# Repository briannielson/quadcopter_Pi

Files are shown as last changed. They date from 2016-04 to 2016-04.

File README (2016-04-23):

PiCopter v0.1

Ground Control is a Linux based controller to parse linux kernel events and send out Yaw, Pitch, Roll data over UDP.

Pi Control is a Raspbian based quad controller to receive input from the Ground Control module and translate output to the individual motors.

Pi Control contains a sub module called imu_sensor, being a modified version of Richard Hirst's modified version of Jeff Rowberg's I2CdevLib.

To setup, you need to:
	- Deploy ground control to your controller
		- Modify controller.c to point to your device
			Line 49: char * fd_source = "/dev/input/event10";
		- Modify udpclient.c to point to your Pi Copter
			Line 29: host= (struct hostent *) gethostbyname((char *)"192.168.1.2");
		- run "make" in the directory ground_control
			-- This compiled on Ubuntu 15.10. This was not tested on any other release.
			-- On other Linux releases, you may or may not need to have the gcc 
			-- option '-D_GNU_SOURCE' in the Makefile.
	- Deploy Pi Control to your Pi Copter
		- run "make" in the directory pi_control
			-- This compiled on Ubuntu 15.10. This was not tested on any other release.
			-- On other Linux releases, you may or may not need to have the gcc 
			-- option '-D_GNU_SOURCE' in the Makefile.
		- run "make" in the directory pi_control/imu_sensor
			-- THIS IS C++ CODE AND A MAJORITY OF IT IS NOT OFFICIALLY PART OF MY RELEASE.
			-- USE AT YOUR OWN RISK. REPORT ANY BUGS TO Richard Hirst (his README is included)

To run:
	- run "sudo ./dmp" in the directory "pi_control/imu_sensor"
	- in another terminal, run "sudo ./control" in the directory "pi_control"
	- on your laptop (ground control), run "sudo ./control" in the directory "ground_control"
	
Hardware:
	- Raspberry Pi B+
	- 12A BLHELI ESC x4
	- Arris MT1806 brushless motor x4
	- 5030 5x3 Propellors x8
	- SanDisk 8GB Class 10 MicroSDHC
	- ARRIS 200x300x3.0mm Carbon Fiber Plate
	- Addicore 5V 1.5A Voltage Regulator L7805CV
	- SMAKN Arduino GY-521 MPU6050 IMU
	- Arducam 5mp OV5647 Mini Camera
	- Venom 20C 3S 2100mAh 11.1V LiPo Battery
	
Compiled and written by Brian Bauman, with significant assistance based on other projects. Freely available to anyone to mess with. If you have any questions, shoot me an email (brian.bauman@cmich.edu), or post an issue on my github. If you need some help deploying this to your own quad, I can lend some assistance, but honestly do not run this version of the code. The PID control is currently out of whack and can be EXTREMELY dangerous (I was in the hospital earlier today because the algorithm exploded and the quad took a decent chunk of my finger off).

I do not take any responsibility in the event of any injuries if you use this project.

PiCopter
--ground_control
	-- main: Starts threads, critical variables, and atomic functions for critical values
	-- controller: Reads input from /dev/input/event** and sets critical variables
	-- udpclient: Reads critical variables and sends yaw, pitch, and roll values to quad
-- pi_control
	-- main: Starts threads, critical variables, and atomic functions for critical values
	-- motorout: Translates input from critical variables to PWM outputs. Also contains PID algorithms currently
	-- server: Listens on port 5000 by default for control information from ground_control
	-- pwm: library used in RPIO (http://pythonhosted.org/RPIO)
	-- imu_sensor
		-- MPU6050, MPU76050_6Axis_MotionApps20: Contains DMP bits to program MPU6050, as well as core functions
		-- helper_3d_math: used to calculate quaternions, euler, and orientation data from raw MPU6050 data
		-- I2Cdev: I2CdevLib for basic I2C communication
		-- dmp: translated Arduino sketch to work in C++, currently configured to write yaw, pitch, roll values to imuData
		-- imuData: data output file to send data from C++ to C program (pi_control/motorout.c)

Resources / code used:

https://solenerotech1.wordpress.com/2013/09/09/tutorialhow-to-control-a-brushless-motor-with-raspberry-pi/ 
https://pythonhosted.org/RPIO/pwm_py.html 
https://www.cdiweb.com/datasheets/invensense/MPU-6050_DataSheet_V3 4.pdf 
http://www.i2cdevlib.com/devices/mpu6050#source 
https://github.com/jrowberg/i2cdevlib/tree/master/Arduino/MPU6050
http://matrixsust.blogspot.com/2011/10/udp-server-client-in-c.html 
https://github.com/metachris/RPIO/tree/master/source/c_pwm 
https://github.com/richardghirst/PiBits/tree/master/MPU6050-Pi-Demo 
http://ctms.engin.umich.edu/CTMS/index.php?example=Introduction&section=ControlPID 
http://www.linuxjournal.com/article/6429

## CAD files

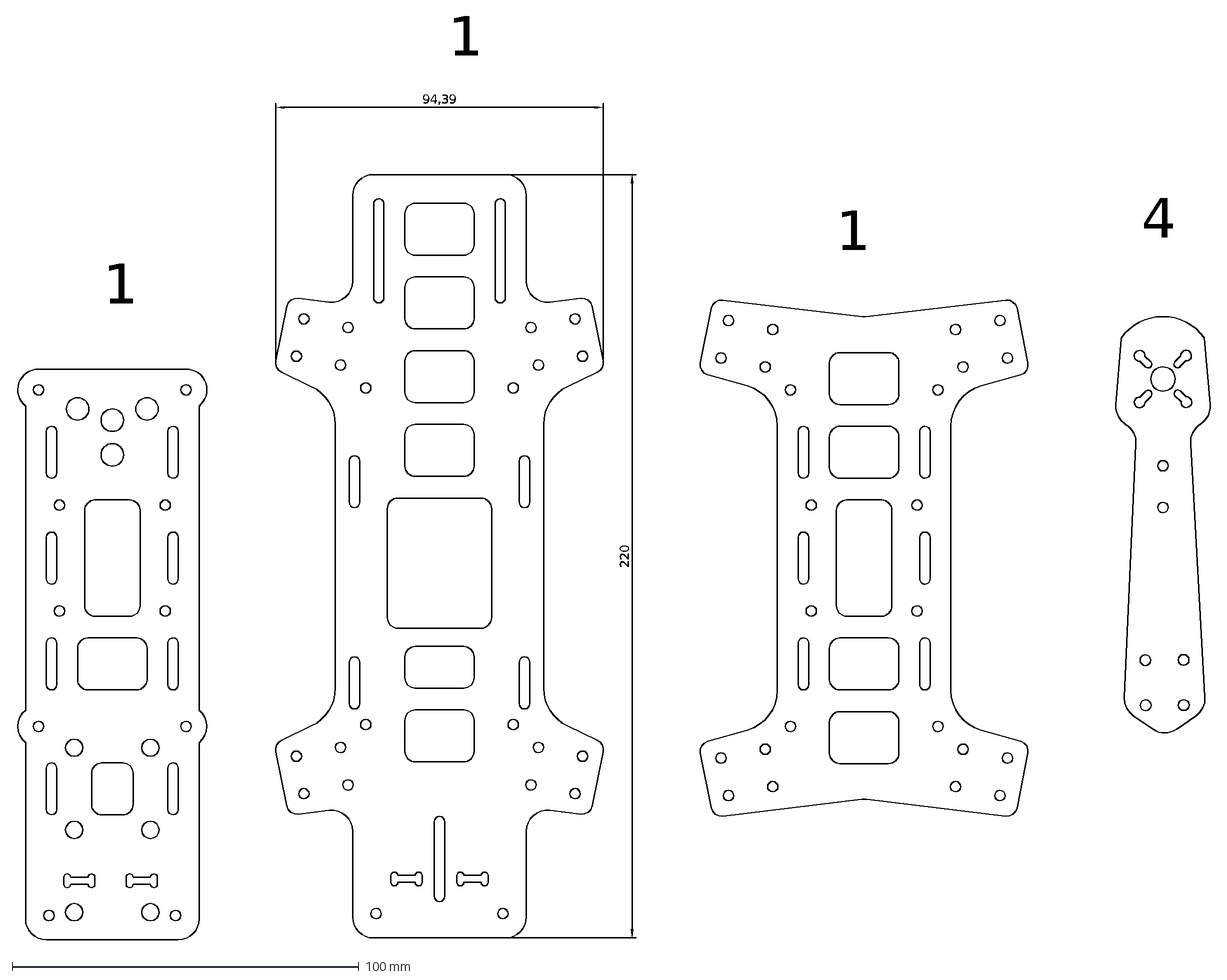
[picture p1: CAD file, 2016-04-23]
composite.dxf
220
94,39
1
4

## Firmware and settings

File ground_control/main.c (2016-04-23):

/*
 * @author: Brian Bauman
 *
 * main program to allow writing from
 * controller to the shared struct which
 * stores the axes values and reading
 * from the UDP client to send values
 * to the server.
 */

#include <stdio.h>
#include <pthread.h>
#include <signal.h>
#include <unistd.h>
#include "controller.h"
#include "udpclient.h"
#include "main.h"
#include <stdatomic.h>

volatile sig_atomic_t stop = 0;
atomic_int lock = 1;

void sigterm_catch(int signum)
{
	stop = 1;
}

int main(void)
{
	joysticks.roll = 0;
	joysticks.throttle = 0;
	joysticks.yaw = 0;
	joysticks.pitch = 0;

	pthread_t pth_ctrl;
	pthread_t pth_udp;

	// worker thread for controller
	pthread_create(&pth_ctrl, NULL, controller_mod, 0);
	sleep(2);
	pthread_create(&pth_udp, NULL, udp_client, 0);

	signal(SIGINT, sigterm_catch);

	while (!stop);

	printf("Terminating threads...\n");

	pthread_join(pth_ctrl, NULL);
	pthread_join(pth_udp, NULL);

	release();

	return 0;
}

void wait(void)
{
	while (lock < 1);
	lock-=1;
}

void release(void)
{
	lock+=1;
}

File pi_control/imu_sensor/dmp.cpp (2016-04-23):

#include <stdio.h>
#include <stdlib.h>
#include <unistd.h>
#include <stdint.h>
#include <string.h>
#include <math.h>
#include "I2Cdev.h"
#include "MPU6050_6Axis_MotionApps20.h"
#include <iostream>
#include <fstream>
using namespace std;

// class default I2C address is 0x68
// specific I2C addresses may be passed as a parameter here
// AD0 low = 0x68 (default for SparkFun breakout and InvenSense evaluation board)
// AD0 high = 0x69
MPU6050 mpu;

// uncomment "OUTPUT_READABLE_QUATERNION" if you want to see the actual
// quaternion components in a [w, x, y, z] format (not best for parsing
// on a remote host such as Processing or something though)
//#define OUTPUT_READABLE_QUATERNION

// uncomment "OUTPUT_READABLE_EULER" if you want to see Euler angles
// (in degrees) calculated from the quaternions coming from the FIFO.
// Note that Euler angles suffer from gimbal lock (for more info, see
// http://en.wikipedia.org/wiki/Gimbal_lock)
//#define OUTPUT_READABLE_EULER

// uncomment "OUTPUT_READABLE_YAWPITCHROLL" if you want to see the yaw/
// pitch/roll angles (in degrees) calculated from the quaternions coming
// from the FIFO. Note this also requires gravity vector calculations.
// Also note that yaw/pitch/roll angles suffer from gimbal lock (for
// more info, see: http://en.wikipedia.org/wiki/Gimbal_lock)
#define OUTPUT_READABLE_YAWPITCHROLL

// uncomment "OUTPUT_READABLE_REALACCEL" if you want to see acceleration
// components with gravity removed. This acceleration reference frame is
// not compensated for orientation, so +X is always +X according to the
// sensor, just without the effects of gravity. If you want acceleration
// compensated for orientation, us OUTPUT_READABLE_WORLDACCEL instead.
//#define OUTPUT_READABLE_REALACCEL

// uncomment "OUTPUT_READABLE_WORLDACCEL" if you want to see acceleration
// components with gravity removed and adjusted for the world frame of
// reference (yaw is relative to initial orientation, since no magnetometer
// is present in this case). Could be quite handy in some cases.
//#define OUTPUT_READABLE_WORLDACCEL

// uncomment "OUTPUT_TEAPOT" if you want output that matches the
// format used for the InvenSense teapot demo
//#define OUTPUT_TEAPOT

// MPU control/status vars
bool dmpReady = false;  // set true if DMP init was successful
uint8_t mpuIntStatus;   // holds actual interrupt status byte from MPU
uint8_t devStatus;      // return status after each device operation (0 = success, !0 = error)
uint16_t packetSize;    // expected DMP packet size (default is 42 bytes)
uint16_t fifoCount;     // count of all bytes currently in FIFO
uint8_t fifoBuffer[64]; // FIFO storage buffer

// orientation/motion vars
Quaternion q;           // [w, x, y, z]         quaternion container
VectorInt16 aa;         // [x, y, z]            accel sensor measurements
VectorInt16 aaReal;     // [x, y, z]            gravity-free accel sensor measurements
VectorInt16 aaWorld;    // [x, y, z]            world-frame accel sensor measurements
VectorFloat gravity;    // [x, y, z]            gravity vector
float euler[3];         // [psi, theta, phi]    Euler angle container
float ypr[3];           // [yaw, pitch, roll]   yaw/pitch/roll container and gravity vector

// packet structure for InvenSense teapot demo
uint8_t teapotPacket[14] = { '$', 0x02, 0,0, 0,0, 0,0, 0,0, 0x00, 0x00, '\r', '\n' };


// ================================================================
// ===                      INITIAL SETUP                       ===
// ================================================================

void setup() {
    // initialize device
    printf("Initializing I2C devices...\n");
    mpu.initialize();

    // verify connection
    printf("Testing device connections...\n");
    printf(mpu.testConnection() ? "MPU6050 connection successful\n" : "MPU6050 connection failed\n");

    // load and configure the DMP
    printf("Initializing DMP...\n");
    devStatus = mpu.dmpInitialize();
    
    // make sure it worked (returns 0 if so)
    if (devStatus == 0) {
        // turn on the DMP, now that it's ready
        printf("Enabling DMP...\n");
        mpu.setDMPEnabled(true);

        // enable Arduino interrupt detection
        //Serial.println(F("Enabling interrupt detection (Arduino external interrupt 0)..."));
        //attachInterrupt(0, dmpDataReady, RISING);
        mpuIntStatus = mpu.getIntStatus();

        // set our DMP Ready flag so the main loop() function knows it's okay to use it
        printf("DMP ready!\n");
        dmpReady = true;

        // get expected DMP packet size for later comparison
        packetSize = mpu.dmpGetFIFOPacketSize();
    } else {
        // ERROR!
        // 1 = initial memory load failed
        // 2 = DMP configuration updates failed
        // (if it's going to break, usually the code will be 1)
        printf("DMP Initialization failed (code %d)\n", devStatus);
    }
}


// ================================================================
// ===                    MAIN PROGRAM LOOP                     ===
// ================================================================
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

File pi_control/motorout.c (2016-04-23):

/*
 * @author: Brian Bauman
 *
 * Translate roll, pitch, yaw, and throttle (thrust)
 * character values from raw input to output
 * to the different ESCs
 */

#include <limits.h>
#include <stdlib.h>
#include <stdio.h>
#include <string.h>
#include "pwm.h"
#include "main.h"
#include "motorout.h"

struct motorprop {
	int gpio;
	int channel;
	int power;
};

FILE *fp;
char buffer[64];

// pid values
float pid_Kp = 0.005;
float pid_Ki = 0.0005;
float pid_Kd = 0.001;
float pid_out = 0;

// pid vars
float Ki_sum = 0;
float Kd_oldDiff = 0;

void *motorout (void *arg)
{
	struct motorprop m1 = { 22, 0, 0 };
	struct motorprop m2 = { 18, 0, 0 };
	struct motorprop m3 = { 27, 0, 0 };
	struct motorprop m4 = { 17, 0, 0 };

	setup(PULSE_WIDTH_INCREMENT_GRANULARITY_US_DEFAULT, DELAY_VIA_PWM);

	// initialize channels
	init_channel(m1.channel, SUBCYCLE_TIME_US_DEFAULT);

	// sleep for 5 seconds after init
	sleep(5);

	// then add max value pulse to set max range
	add_channel_pulse(m1.channel, m1.gpio, 0, 200);
        add_channel_pulse(m2.channel, m2.gpio, 0, 200);
        add_channel_pulse(m3.channel, m3.gpio, 0, 200);
        add_channel_pulse(m4.channel, m4.gpio, 0, 200);

	// sleep for 1 second to allow ESC to calibrate
	sleep(1);

	// clear all channels
	clear_channel_gpio(m1.channel, m1.gpio);
        clear_channel_gpio(m2.channel, m2.gpio);
        clear_channel_gpio(m3.channel, m3.gpio);
        clear_channel_gpio(m4.channel, m4.gpio);

	set_loglevel(2);

	// sleep for 5 seconds
	sleep(5);
	printf("Armed.\n");

	// ready for action
	while(!stop) {
		calculate_power(&m1.power, &m2.power, &m3.power, &m4.power);
		add_channel_pulse(m1.channel, m1.gpio, 0, m1.power);
       		add_channel_pulse(m2.channel, m2.gpio, 0, m2.power);
       	 	add_channel_pulse(m3.channel, m3.gpio, 0, m3.power);
	        add_channel_pulse(m4.channel, m4.gpio, 0, m4.power);
		//printf("m1: %3d, m2: %3d, m3: %3d, m4: %3d\r", m1.power, m2.power, m3.power, m4.power);
	}

        clear_channel_gpio(m1.channel, m1.gpio);
        clear_channel_gpio(m2.channel, m2.gpio);
        clear_channel_gpio(m3.channel, m3.gpio);
        clear_channel_gpio(m4.channel, m4.gpio);

	shutdown();
	exit(0);
}

/*    1     2
 *     \   /
 *      |||
 *      |||
 *      |||
 *     /   \
 *    3     4
 */

void calculate_power(int *m1p, int *m2p, int *m3p, int *m4p)
{
	int proll, ppitch, pyaw;
	signed char pitch, roll, yaw, throttle;
	int throttleOut;

	fp = fopen("/home/brian/imu_sensor/imuData", "r");
	if (fp > 0) {
		if (fread(buffer, 20, 1, fp) > 0) {

			float ypr[3] = {0};
			int i = 0;

			//if (n >= 0) printf("%s\n", buffer);

			char *token = strtok(buffer, "/ \r\n");
			//printf("tokens:\n");
			while (token != NULL && i < 3) {
				//printf("%s\n", token);
				ypr[i] = strtof(token, NULL);
				token = strtok(NULL, "/ \r\n");
				i++;
			}

			if (imu.yaw == 0) imu.yaw = ypr[0];
			imu.pitch = ypr[1] + 2.;
			imu.roll  = -1 * ypr[2] + 2.;
		}
	} fclose(fp);
	//printf("%8.3f, %8.3f, %8.3f\n", ypr[0], ypr[1], ypr[2]);

	wait();
	//printf("throttle input: %d\n", motor.throttle);
	throttle = motor.throttle < 0 ? ~motor.throttle : 0;
	roll = ~motor.roll / 2;
	pitch = motor.pitch / 2;
	yaw = ~motor.yaw / 2;
	release();

	// override for stable testing
	roll = 0;
	pitch = 0;
	yaw = 0;

	//printf("throttle: %3d, pitch: %3d, roll: %3d, yaw: %3d\n", throttle, pitch, roll, yaw);
	//printf("complement:    pitch: %3d, roll: %3d, yaw: %3d\n", ~pitch, ~roll, ~yaw);

	// map throttle between 100-200
	throttleOut = ((float) throttle / 128) * 100 + 100;

	//printf("ThrottleOutput: %4d, Yaw: %4.2f, Pitch: %4.2f, Roll: %4.2f\r", throttleOut, imu.yaw, imu.pitch, imu.roll);

	// calculate pid values
	proll = throttleOut > 130 ? calculate_pid(imu.roll) : 0;
	pyaw = throttleOut > 130 ? calculate_pid(imu.yaw) : 0;
	ppitch = throttleOut > 130 ? calculate_pid(imu.pitch) : 0;

	*m1p = throttleOut - ppitch + proll + pyaw;
        *m2p = throttleOut - ppitch - proll - pyaw;
        *m3p = throttleOut + ppitch + proll - pyaw;
        *m4p = throttleOut + ppitch - proll + pyaw;
}

void set_prop_gain (float kp) {
	pid_Kp = kp;
}

void set_int_gain (float kint) {
	pid_Ki = kint;
}

void set_der_gain (float kder) {
	pid_Kd = kder;
}

int calculate_pid (float ori_target) {
	// ori_target : Where I want to be in orientation
	// ori : Where I am currently
	pid_out = 0;

	float error = ori_target;
	float deltaDiff;
	float pidTemp;

	// proportional
	pidTemp = pid_Kp * error;
	if (pidTemp > 4.) pidTemp = 4.;
	else if (pidTemp < -4.) pidTemp = -4.;

	pid_out += pidTemp;

	// integral
	Ki_sum += pid_Ki * error;
	if (Ki_sum > 4.) Ki_sum = 4.;
	else if (Ki_sum < 4.) Ki_sum = -4.;

	pid_out += Ki_sum;

	// derivative
	deltaDiff = pid_Kd * (Kd_oldDiff - error);
	Kd_oldDiff = error;
	if (deltaDiff > 4.) deltaDiff = 4;
	else if (deltaDiff < -4.) deltaDiff = -4;

	pid_out += deltaDiff;

	//printf("PID_P: %6.2f, PID_I: %6.2f, PID_D: %6.2f\n", pidTemp, Ki_sum, deltaDiff);

	return (int) pid_out;
}
